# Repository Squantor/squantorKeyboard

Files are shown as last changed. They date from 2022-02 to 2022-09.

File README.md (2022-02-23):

# My own keyboard stuff
This repository contains my experiments on creating my own keyboard electronics and software.
## Structure
* [electronics](electronics/README.md) contains keyboard circuits boards and possible controllers.
* [software](software/README.md) contains all the software used in the project. This can be embedded, PC/smartphone or test scripts, anything a computer can execute resides here.
* [mechanical](mechanical/README.md) contains all the CAD drawings, mostly 3d printable objects.
* [documentation](documentation/index.md) contains all project documentation, logs, research, papers, datasheets and more.
## Cloning
This repository makes extensive use of submodules, use ```git clone --recurse-submodules https://github.com/Squantor/squantorKeyboard.git``` to clone everything in one go.
# TODOs
Open tasks

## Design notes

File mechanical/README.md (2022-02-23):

# Keyboard mechanical parts
All mechanical components used in the project reside here.
## Mechanical parts
* [left switch plate](split_ortho_left/README.md) of a split ortholinear keyboard

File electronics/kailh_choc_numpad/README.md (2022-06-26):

# Kailh Choc numpad tryout
Trying out kailh choc numpad with using 2 port expanders
# HSI (Hardware Software Interface)
* 16 bit port expander at address 0x??
	* Pin 0: Row 0 drive
	* Pin 1: Row 1 drive
	* Pin 2: Row 2 drive
	* Pin 3: Row 2 drive
	* Pin 4: Row 2 drive
	* Pin 8: Column 0 LED drive, pulled up by 100K
	* Pin 9: Column 1 LED drive, pulled up by 100K
	* Pin 10: Column 2 LED drive, pulled up by 100K
	* Pin 11: Column 3 LED drive, pulled up by 100K
* 8 bit port expander at address 0x??
	* Pin 0: Column 0 switch sense, pulled up by 4.7K
	* Pin 1: Column 1 switch sense, pulled up by 4.7K
	* Pin 2: Column 2 switch sense, pulled up by 4.7K
	* Pin 3: Column 3 switch sense, pulled up by 4.7K
Matrix switches and definitions:
TODO
## TODO's
Still some things need to be done:
* schematic entry
* expand HSI 
* PCB layout
* Review with one night in between
* Produce at [OSHPARK](https://oshpark.com/)
* Assemble
* Test & characterise
* update Readme.md with pictures and BOM
## BOM
* TODO: 16 bit port expander
* TODO: 8 bit port expander
* TODO: Kailh choc 1350 switches
* TODO: keycaps from kailhua for kailh choc keys

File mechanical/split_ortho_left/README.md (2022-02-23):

# Left switch plate ortholinear keyboard
This is the left side switch plate of a split ortholinear keyboard.

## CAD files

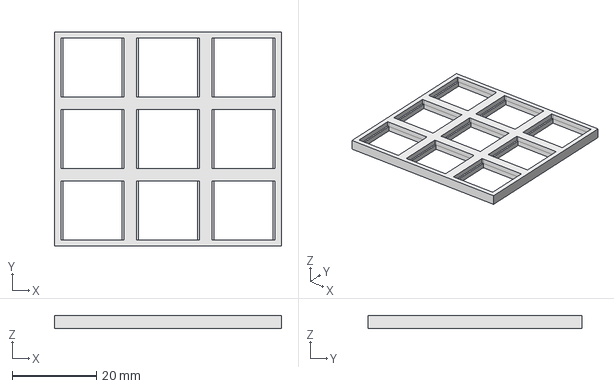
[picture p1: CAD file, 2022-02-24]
mechanical/3by3_9switch_ortho/3by3_9switch_ortho.FCStd
54.0 x 51.0 x 3.00 mm

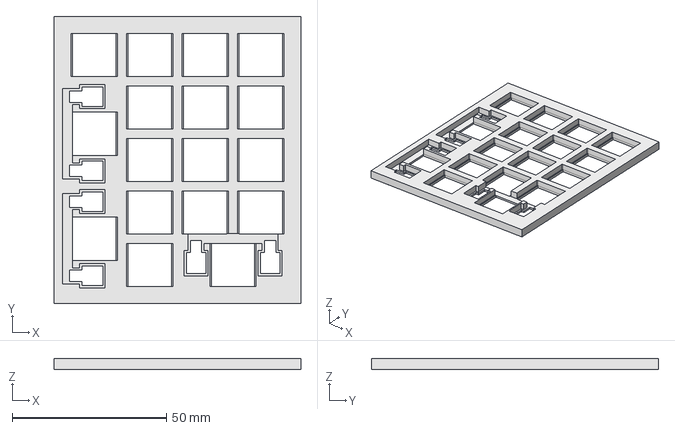
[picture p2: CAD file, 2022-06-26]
mechanical/choc_numpad/choc_numpad.FCStd
80.0 x 93.0 x 3.50 mm

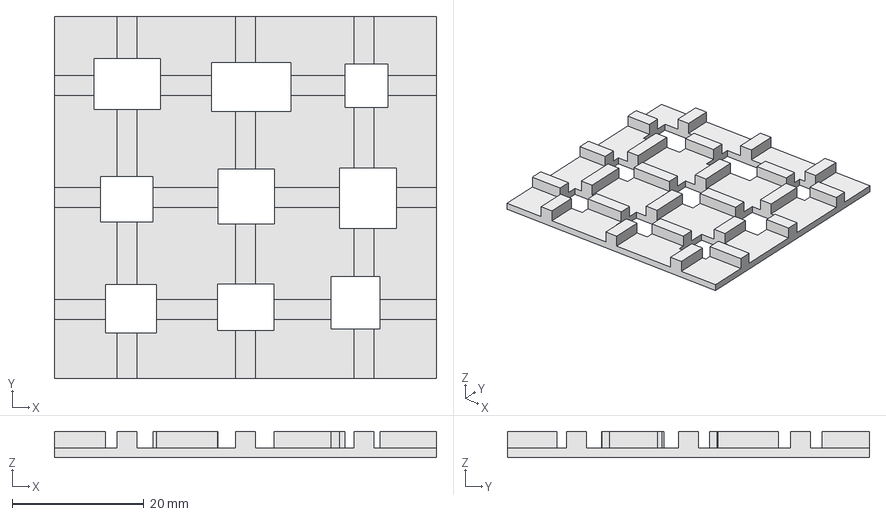
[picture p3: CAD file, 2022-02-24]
mechanical/split_ortho_left/split_ortho_left.FCStd
58.0 x 55.0 x 4.00 mm

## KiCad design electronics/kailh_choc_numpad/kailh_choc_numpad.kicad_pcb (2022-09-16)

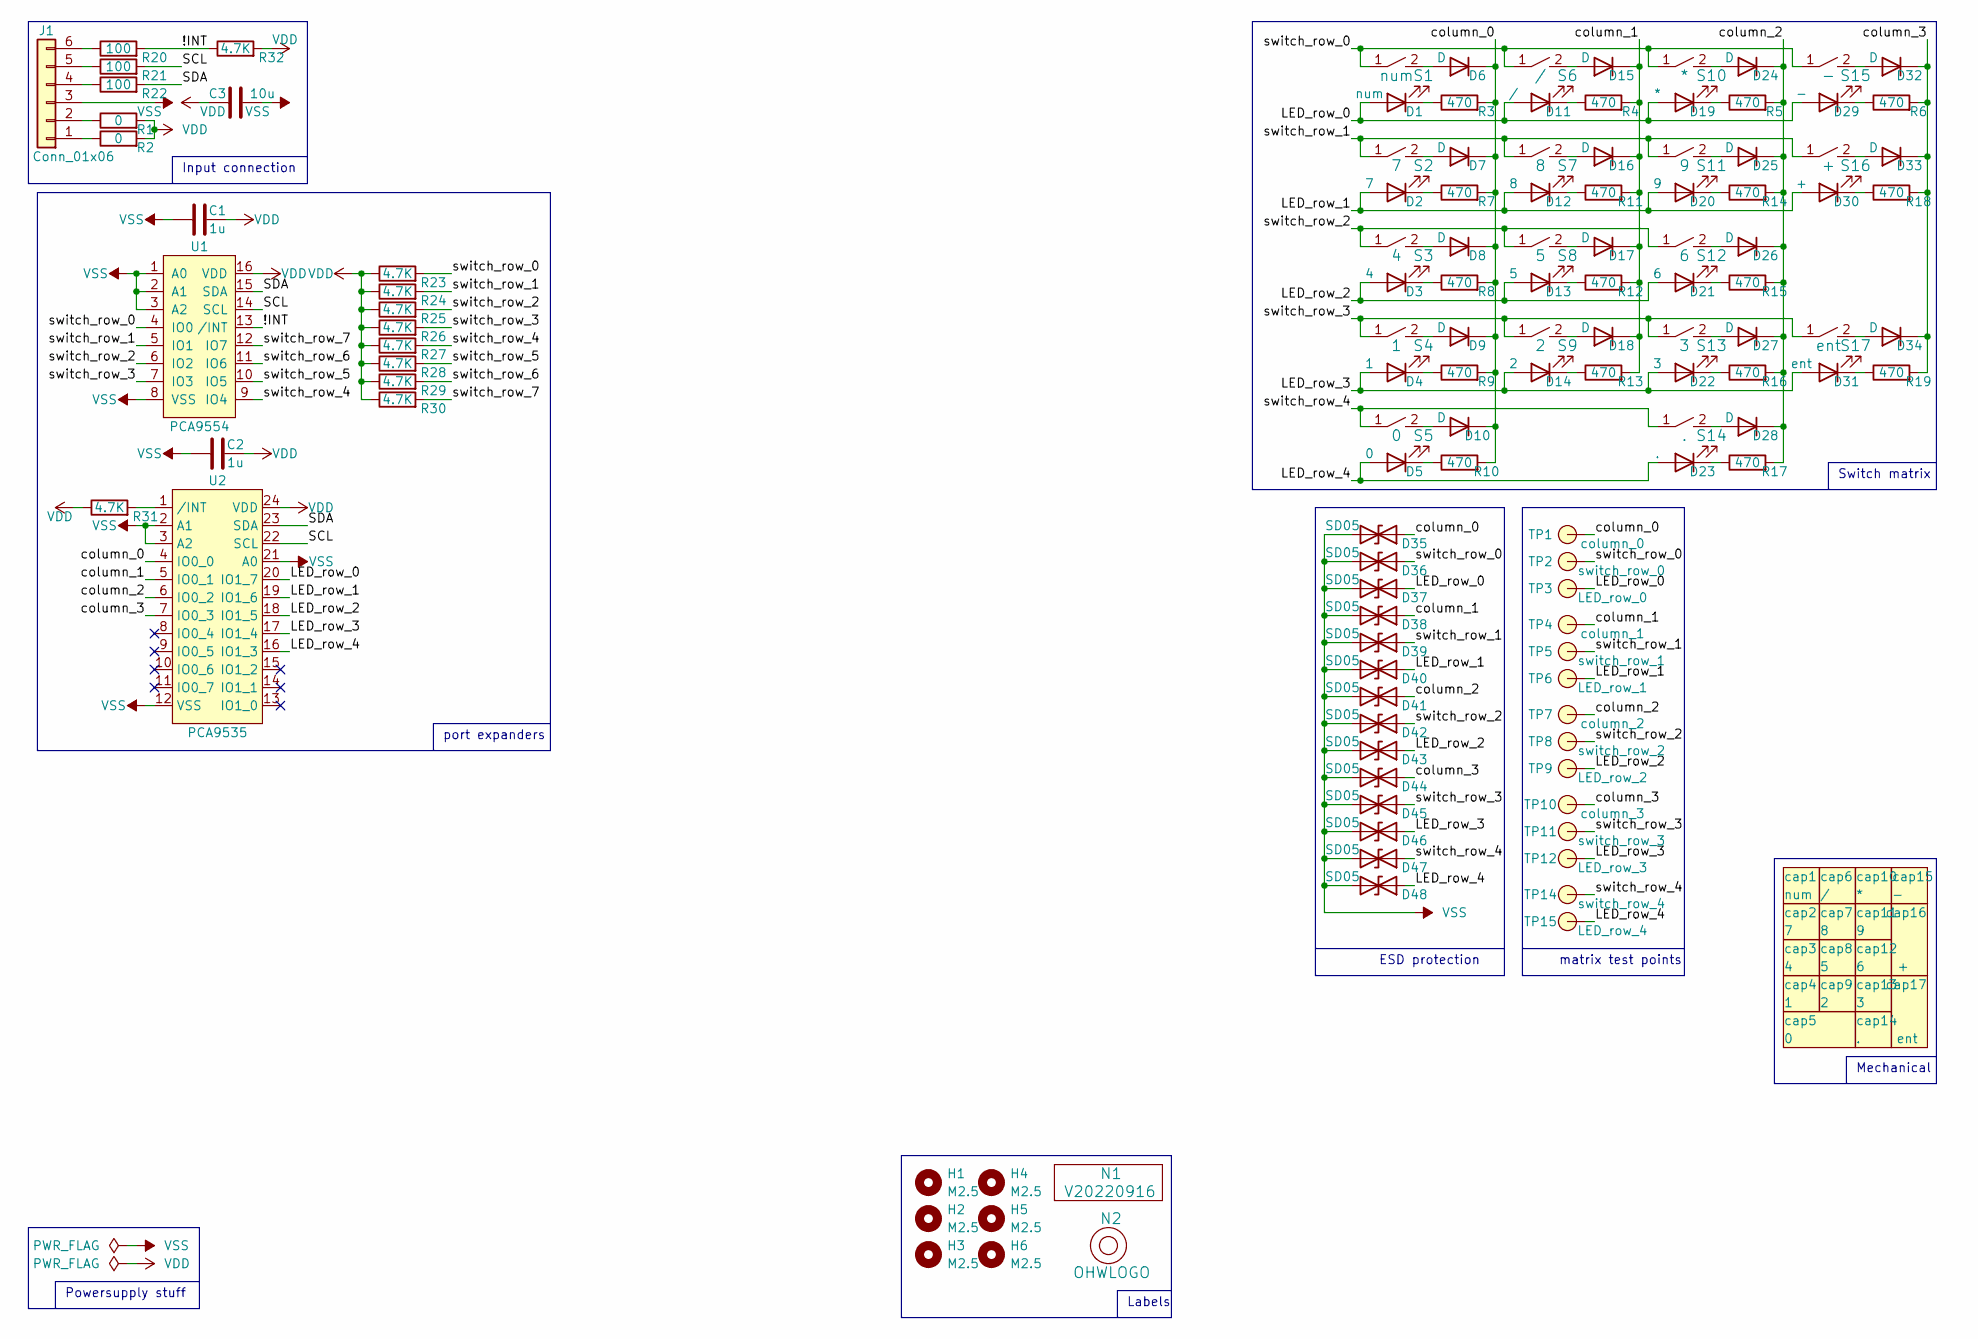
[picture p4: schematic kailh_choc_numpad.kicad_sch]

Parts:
C1, C2: 1u; C_0603
C3: 10u; C_0805
D1: num; LED_1208_0603
D2: 7; LED_1208_0603
D3: 4; LED_1208_0603
D4: 1; LED_1208_0603
D5: 0; LED_1208_0603
D6, D7, D8, D9, D10, D15, D16, D17, D18, D24, D25, D26, D27, D28, D32, D33, D34: D; SOD-523_hand
D11: /; LED_1208_0603
D12: 8; LED_1208_0603
D13: 5; LED_1208_0603
D14: 2; LED_1208_0603
D19: *; LED_1208_0603
D20: 9; LED_1208_0603
D21: 6; LED_1208_0603
D22: 3; LED_1208_0603
D23: .; LED_1208_0603
D29: -; LED_1208_0603
D30: +; LED_1208_0603
D31: ent; LED_1208_0603
D35, D36, D37, D38, D39, D40, D41, D42, D43, D44, D45, D46, D47, D48: SD05; D_SOD-323
H1, H2, H3, H4, H5, H6: M2.5; MountingHole_2.7mm_M2.5
J1: Conn_01x06; JST_PH_S6B-PH-K_1x06_P2.00mm_Horizontal
N1: V20220916; Label_Generic
N2: OHWLOGO; OSHW-Symbol_8.9x8mm_SilkScreen
R1, R2: 0; R_0603_hand
R3, R4, R5, R6, R7, R8, R9, R10, R11, R12, R13, R14, R15, R16, R17, R18, R19: 470; R_0603_hand
R20, R21, R22: 100; R_0603_hand
R23, R24, R25, R26, R27, R28, R29, R30, R31, R32: 4.7K; R_0603_hand
S1: num; KAILH_choc_LED
S2: 7; KAILH_choc_LED
S3: 4; KAILH_choc_LED
S4: 1; KAILH_choc_LED
S5: 0; KAILH_choc_LED
S6: /; KAILH_choc_LED
S7: 8; KAILH_choc_LED
S8: 5; KAILH_choc_LED
S9: 2; KAILH_choc_LED
S10: *; KAILH_choc_LED
S11: 9; KAILH_choc_LED
S12: 6; KAILH_choc_LED
S13: 3; KAILH_choc_LED
S14: .; KAILH_choc_LED
S15: -; KAILH_choc_LED
S16: +; KAILH_choc_LED
S17: ent; KAILH_choc_LED
TP1: column_0; TestPoint_hole_H05R10
TP2: switch_row_0; TestPoint_hole_H05R10
TP3: LED_row_0; TestPoint_hole_H05R10
TP4: column_1; TestPoint_hole_H05R10
TP5: switch_row_1; TestPoint_hole_H05R10
TP6: LED_row_1; TestPoint_hole_H05R10
TP7: column_2; TestPoint_hole_H05R10
TP8: switch_row_2; TestPoint_hole_H05R10
TP9: LED_row_2; TestPoint_hole_H05R10
TP10: column_3; TestPoint_hole_H05R10
TP11: switch_row_3; TestPoint_hole_H05R10
TP12: LED_row_3; TestPoint_hole_H05R10
TP14: switch_row_4; TestPoint_hole_H05R10
TP15: LED_row_4; TestPoint_hole_H05R10
U1: PCA9554; SOT403-1-NXP
U2: PCA9535; SOT355-1-NXP
cap1: num; KAILH_choc_keycap_1
cap2: 7; KAILH_choc_keycap_1
cap3: 4; KAILH_choc_keycap_1
cap4: 1; KAILH_choc_keycap_1
cap5: 0; KAILH_choc_keycap_2_horizontal
cap6: /; KAILH_choc_keycap_1
cap7: 8; KAILH_choc_keycap_1
cap8: 5; KAILH_choc_keycap_1
cap9: 2; KAILH_choc_keycap_1
cap10: *; KAILH_choc_keycap_1
cap11: 9; KAILH_choc_keycap_1
cap12: 6; KAILH_choc_keycap_1
cap13: 3; KAILH_choc_keycap_1
cap14: .; KAILH_choc_keycap_1
cap15: -; KAILH_choc_keycap_1
cap16: +; KAILH_choc_keycap_2_vertical
cap17: ent; KAILH_choc_keycap_2_vertical

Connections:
/!INT: R20.2, R32.1, U1.13 (/INT)
/LED_row_0: D1.2 (A), D11.2 (A), D19.2 (A), D29.2 (A), D37.1 (A1), TP3.1, U2.20 (IO1_7)
/LED_row_1: D2.2 (A), D12.2 (A), D20.2 (A), D30.2 (A), D40.1 (A1), TP6.1, U2.19 (IO1_6)
/LED_row_2: D3.2 (A), D13.2 (A), D21.2 (A), D43.1 (A1), TP9.1, U2.18 (IO1_5)
/LED_row_3: D4.2 (A), D14.2 (A), D22.2 (A), D31.2 (A), D46.1 (A1), TP12.1, U2.17 (IO1_4)
/LED_row_4: D5.2 (A), D23.2 (A), D48.1 (A1), TP15.1, U2.16 (IO1_3)
/SCL: R21.2, U1.14 (SCL), U2.22 (SCL)
/SDA: R22.2, U1.15 (SDA), U2.23 (SDA)
/column_0: D6.1 (K), D7.1 (K), D8.1 (K), D9.1 (K), D10.1 (K), D35.1 (A1), R3.2, R7.2, R8.2, R9.2, R10.2, TP1.1, U2.4 (IO0_0)
/column_1: D15.1 (K), D16.1 (K), D17.1 (K), D18.1 (K), D38.1 (A1), R4.2, R11.2, R12.2, R13.2, TP4.1, U2.5 (IO0_1)
/column_2: D24.1 (K), D25.1 (K), D26.1 (K), D27.1 (K), D28.1 (K), D41.1 (A1), R5.2, R14.2, R15.2, R16.2, R17.2, TP7.1, U2.6 (IO0_2)
/column_3: D32.1 (K), D33.1 (K), D34.1 (K), D44.1 (A1), R6.2, R18.2, R19.2, TP10.1, U2.7 (IO0_3)
/switch_row_0: D36.1 (A1), R23.2, S1.1, S6.1, S10.1, S15.1, TP2.1, U1.4 (IO0)
/switch_row_1: D39.1 (A1), R24.2, S2.1, S7.1, S11.1, S16.1, TP5.1, U1.5 (IO1)
/switch_row_2: D42.1 (A1), R25.2, S3.1, S8.1, S12.1, TP8.1, U1.6 (IO2)
/switch_row_3: D45.1 (A1), R26.2, S4.1, S9.1, S13.1, S17.1, TP11.1, U1.7 (IO3)
/switch_row_4: D47.1 (A1), R27.2, S5.1, S14.1, TP14.1, U1.9 (IO4)
/switch_row_5: R28.2, U1.10 (IO5)
/switch_row_6: R29.2, U1.11 (IO6)
/switch_row_7: R30.2, U1.12 (IO7)
unnamed: D1.1 (K), R3.1
unnamed: D2.1 (K), R7.1
unnamed: D3.1 (K), R8.1
unnamed: D4.1 (K), R9.1
unnamed: D5.1 (K), R10.1
unnamed: D6.2 (A), S1.2
unnamed: D7.2 (A), S2.2
unnamed: D8.2 (A), S3.2
unnamed: D9.2 (A), S4.2
unnamed: D10.2 (A), S5.2
unnamed: D11.1 (K), R4.1
unnamed: D12.1 (K), R11.1
unnamed: D13.1 (K), R12.1
unnamed: D14.1 (K), R13.1
unnamed: D15.2 (A), S6.2
unnamed: D16.2 (A), S7.2
unnamed: D17.2 (A), S8.2
unnamed: D18.2 (A), S9.2
unnamed: D19.1 (K), R5.1
unnamed: D20.1 (K), R14.1
unnamed: D21.1 (K), R15.1
unnamed: D22.1 (K), R16.1
unnamed: D23.1 (K), R17.1
unnamed: D24.2 (A), S10.2
unnamed: D25.2 (A), S11.2
unnamed: D26.2 (A), S12.2
unnamed: D27.2 (A), S13.2
unnamed: D28.2 (A), S14.2
unnamed: D29.1 (K), R6.1
unnamed: D30.1 (K), R18.1
unnamed: D31.1 (K), R19.1
unnamed: D32.2 (A), S15.2
unnamed: D33.2 (A), S16.2
unnamed: D34.2 (A), S17.2
unnamed: J1.1, R2.1
unnamed: J1.2, R1.1
unnamed: J1.4, R22.1
unnamed: J1.5, R21.1
unnamed: J1.6, R20.1
unnamed: R31.2, U2.1 (/INT)
VDD: C1.2, C2.2, C3.1, R1.2, R2.2, R23.1, R24.1, R25.1, R26.1, R27.1, R28.1, R29.1, R30.1, R31.1, R32.2, U1.16 (VDD), U2.24 (VDD)
VSS: C1.1, C2.1, C3.2, D35.2 (A2), D36.2 (A2), D37.2 (A2), D38.2 (A2), D39.2 (A2), D40.2 (A2), D41.2 (A2), D42.2 (A2), D43.2 (A2), D44.2 (A2), D45.2 (A2), D46.2 (A2), D47.2 (A2), D48.2 (A2), J1.3, U1.1 (A0), U1.2 (A1), U1.3 (A2), U1.8 (VSS), U2.2 (A1), U2.3 (A2), U2.12 (VSS), U2.21 (A0)

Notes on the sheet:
Labels
Switch matrix
matrix test points
port expanders
Powersupply stuff
Mechanical
Input connection
ESD protection

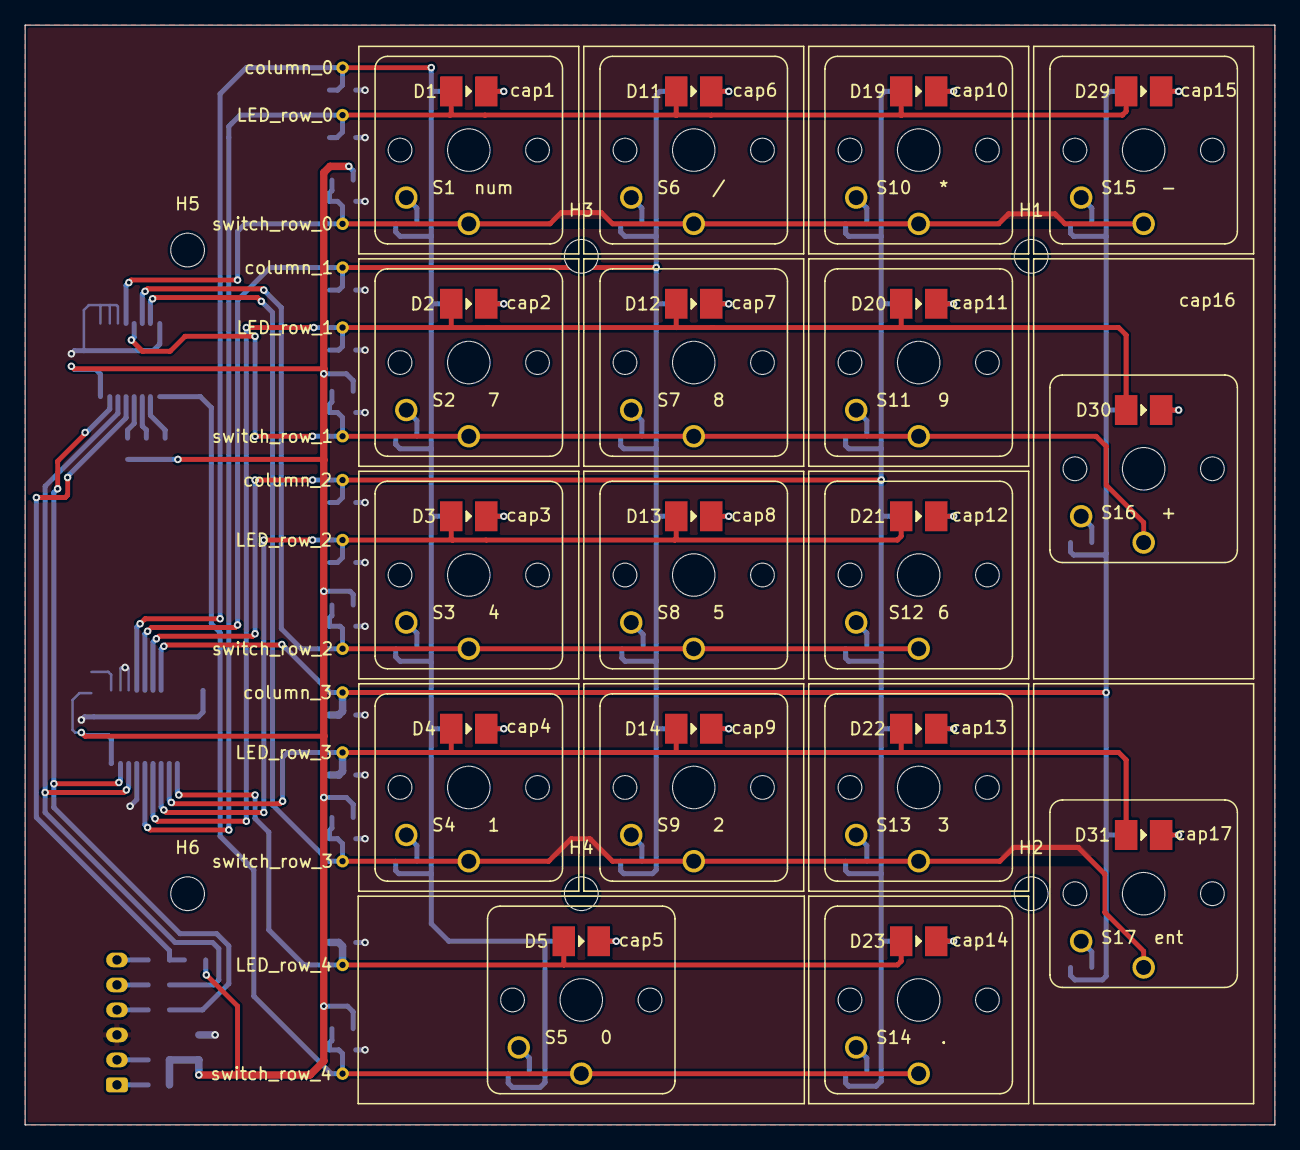
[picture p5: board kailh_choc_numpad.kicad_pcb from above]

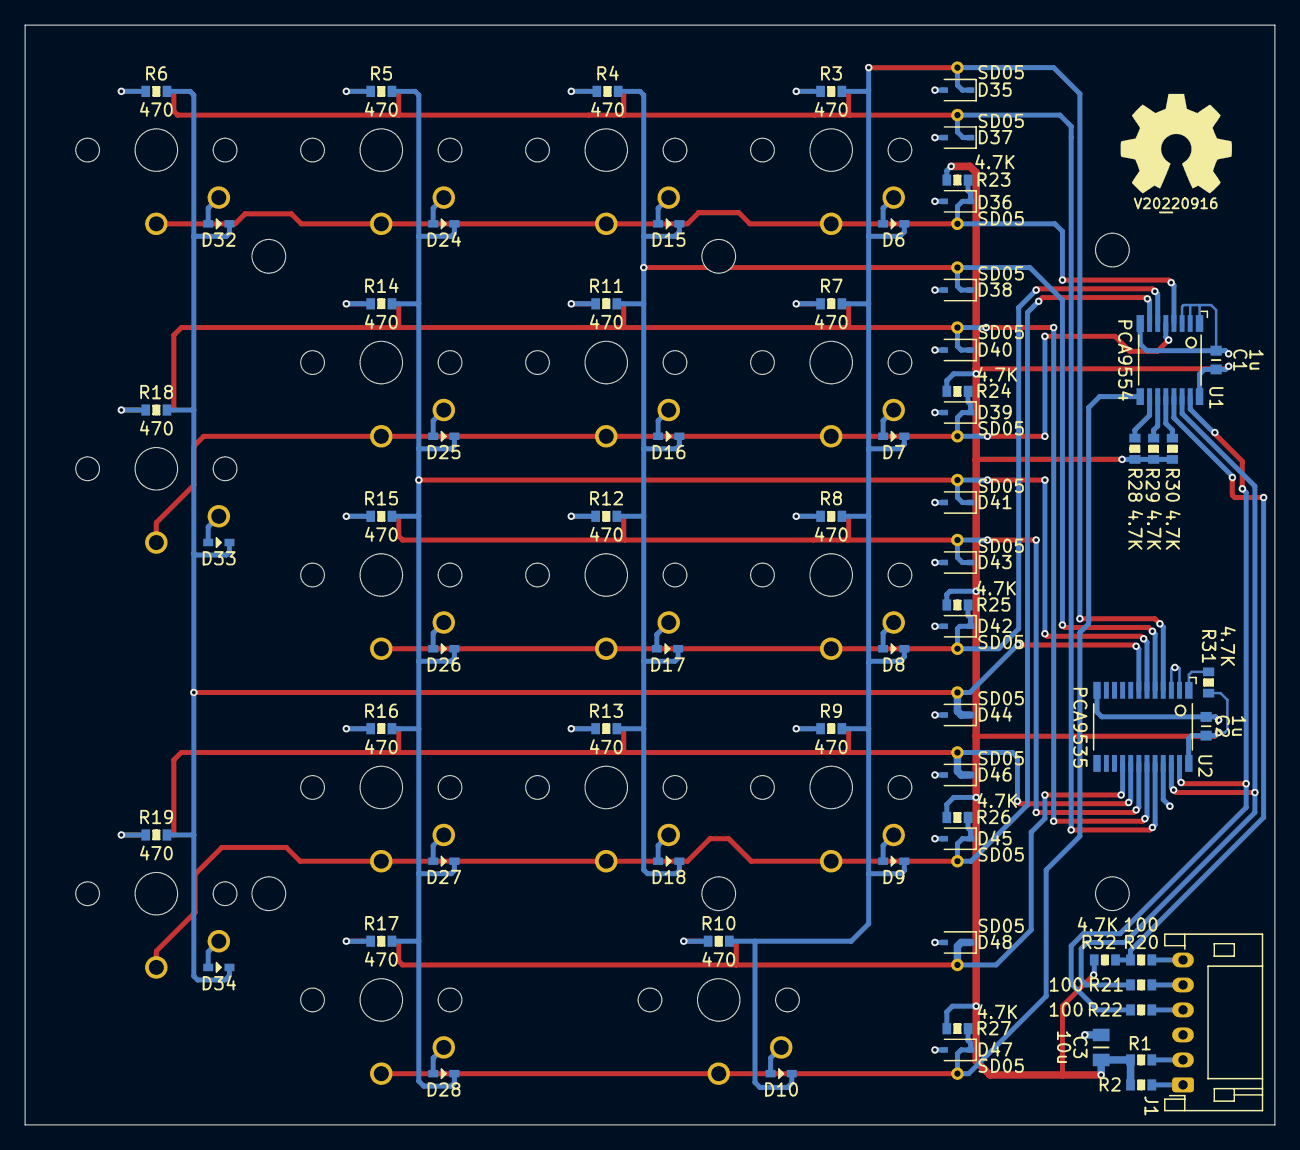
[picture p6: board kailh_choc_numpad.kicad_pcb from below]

Board: 2 copper layers, 100.0 x 88.0 mm, 142 parts (71 on the bottom side), 62 nets.

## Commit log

2022-02-23 started with left side of a split ortholinear keyboard
    [split_ortho_left.FCStd]
2022-02-23 minor changes
    [split_ortho_left.FCStd]
2022-02-24 parking split ortho left, starting with a more grid layout
    [3by3_9switch_ortho.FCStd, split_ortho_left.FCStd]
2022-02-24 updated plate thicknesses and removed borders
    [3by3_9switch_ortho.FCStd]
2022-02-24 further mechanical changes to switch plate
    [3by3_9switch_ortho.FCStd]
2022-06-24 first beginning of kailh choc numpad
    [choc_numpad.FCStd]
2022-06-24 added cutouts for switch clips
    [choc_numpad.FCStd]
2022-06-24 not mirrored now
    [choc_numpad.FCStd]
2022-06-24 WIP: choc numpads
    [choc_numpad.FCStd]
2022-06-25 adjusted dimensions to better fit
    [choc_numpad.FCStd]
2022-06-26 WIP: adjusting stabilizer holes, again
    [choc_numpad.FCStd]
2022-06-26 added pcb library submodule
2022-06-26 started with kailh choc numpad
    [kailh_choc_numpad.kicad_pcb, kailh_choc_numpad.kicad_sch]
2022-06-26 finally got the stabilizer positions and thicknesses correct
    [choc_numpad.FCStd]
2022-06-26 fixed error with footprint table dirs and updated library
2022-06-26 fine tuned dimensions for stabilizers
    [choc_numpad.FCStd]
2022-06-26 placed keycaps
    [kailh_choc_numpad.kicad_pcb, kailh_choc_numpad.kicad_sch]
2022-06-26 Added another kicad temporary
2022-06-26 minor adjustments
    [choc_numpad.FCStd]
2022-06-26 placing and routing keyboard matrix
    [kailh_choc_numpad.kicad_pcb, kailh_choc_numpad.kicad_sch]
2022-06-26 fully placed and routed switch matrix
    [kailh_choc_numpad.kicad_pcb, kailh_choc_numpad.kicad_sch]
2022-06-26 updated diode 3d models
2022-06-26 added, placed and routed ESD diodes
    [kailh_choc_numpad.kicad_pcb, kailh_choc_numpad.kicad_sch]
2022-07-14 Updated PCB library
2022-07-14 added LED resistors
    [kailh_choc_numpad.kicad_sch]
2022-07-14 placed resistors, now routing needed
    [kailh_choc_numpad.kicad_pcb]
2022-07-15 placed and routed LED resistors
    [kailh_choc_numpad.kicad_pcb]
2022-07-15 added i2c port expander but wrong footprint, now
    [kailh_choc_numpad.kicad_pcb, kailh_choc_numpad.kicad_sch]
2022-07-16 added I2C port expanders
    [kailh_choc_numpad.kicad_sch]
2022-07-16 imported I2C expanders, time to route
    [kailh_choc_numpad.kicad_pcb]
2022-07-17 further placing and routing
    [kailh_choc_numpad.kicad_pcb, kailh_choc_numpad.kicad_sch]
2022-07-18 routed all traces
    [kailh_choc_numpad.kicad_pcb]
2022-07-18 saving small changes
    [kailh_choc_numpad.kicad_pcb]
2022-08-24 silk placement completed
    [kailh_choc_numpad.kicad_pcb]
2022-08-24 updated broken IC footprint, added OHW logo
    [kailh_choc_numpad.kicad_pcb, kailh_choc_numpad.kicad_sch]
2022-09-16 added mounting holes
    [kailh_choc_numpad.kicad_pcb, kailh_choc_numpad.kicad_sch]
